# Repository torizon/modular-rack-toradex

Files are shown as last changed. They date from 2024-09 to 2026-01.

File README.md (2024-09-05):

# Modular rack for Toradex boards

This project was created using OpenSCAD, an open-source software for creating 3D CAD solids. With it, you can create a modular rack to stack any Toradex board, either vertically or horizontally. The internal dimensions of each support are adjusted according to the desired board, while the external dimensions remain the same, making it possible to stack these supports.

In the example below, we have the vertical stacking of two support models for Toradex Iris or Mallow boards. The visualization was created using the FreeCAD software.

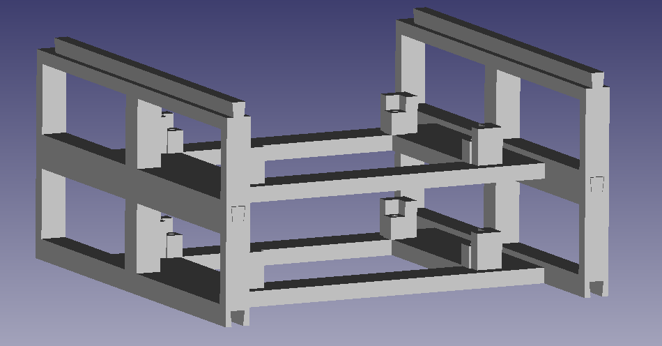
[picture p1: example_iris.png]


It is also possible to use these supports on their side, which significantly improves air circulation. In these cases, it is recommended to use the mounting holes to secure the boards with screws.

The figure below shows a CPU temperature comparison for the Toradex Verdin iMX8MP module, where the temperature differences are clearly noticeable when the rack is positioned vertically (one board on top of the other) or horizontally (one board next to the other).

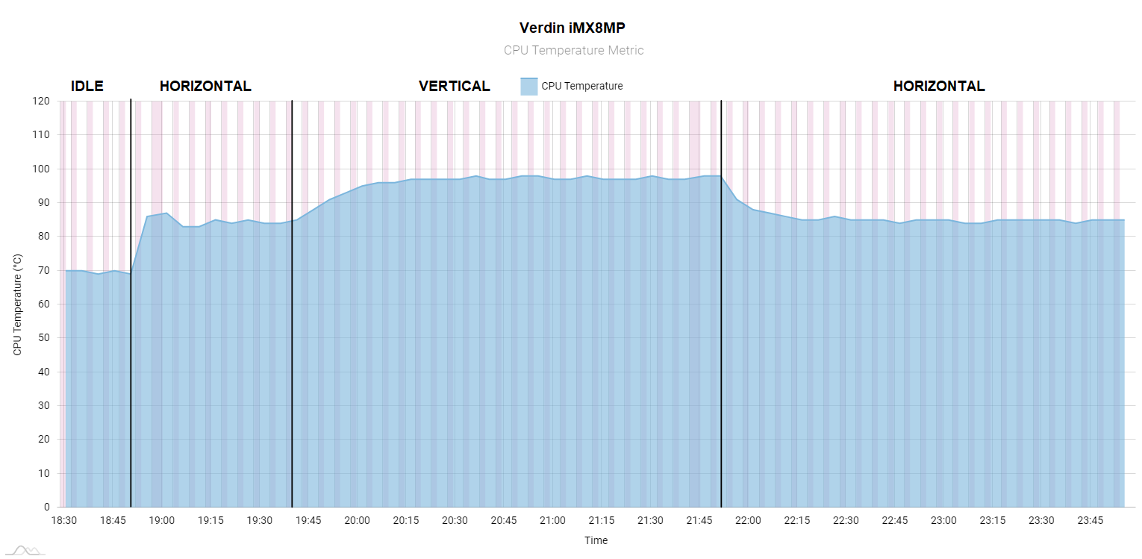
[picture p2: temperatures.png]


## How to use

To select your board, you must include the desired board on the first lines of `main.scad` file. The dimensions of each board can be found in the `boards_dimensions directory`. After that, export the STL file and use your preferred slicer to create the file for printing.

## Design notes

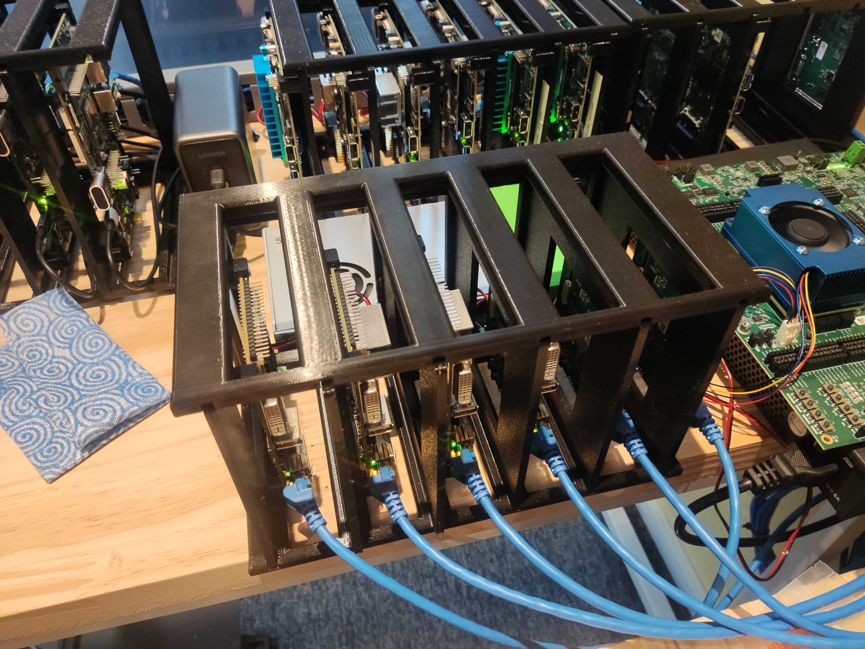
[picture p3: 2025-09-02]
v2/photos/example3.jpg

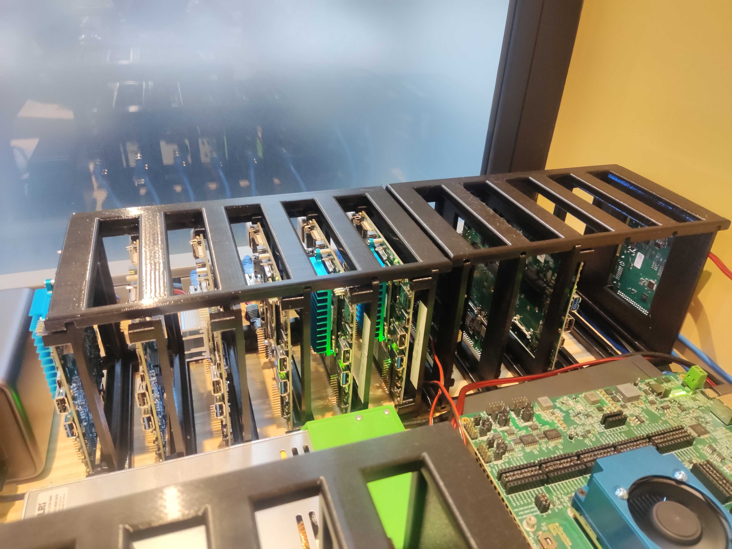
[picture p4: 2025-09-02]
v2/photos/example2.jpg

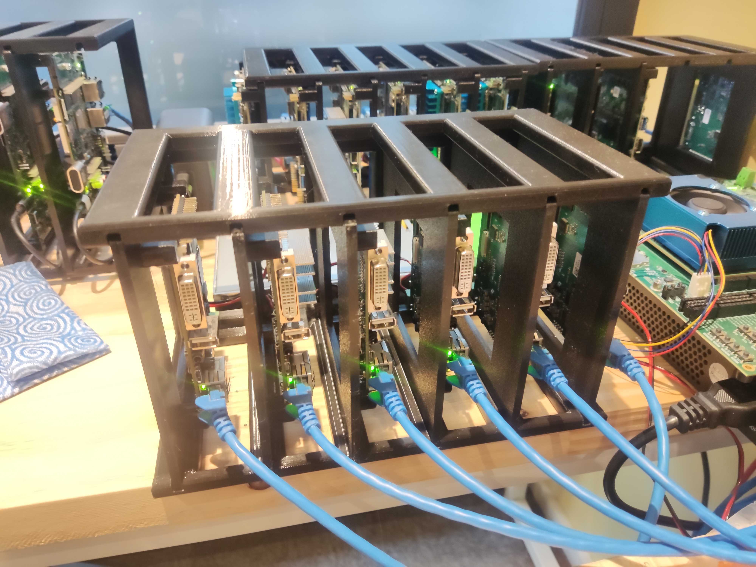
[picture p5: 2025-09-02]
v2/photos/example1.jpg

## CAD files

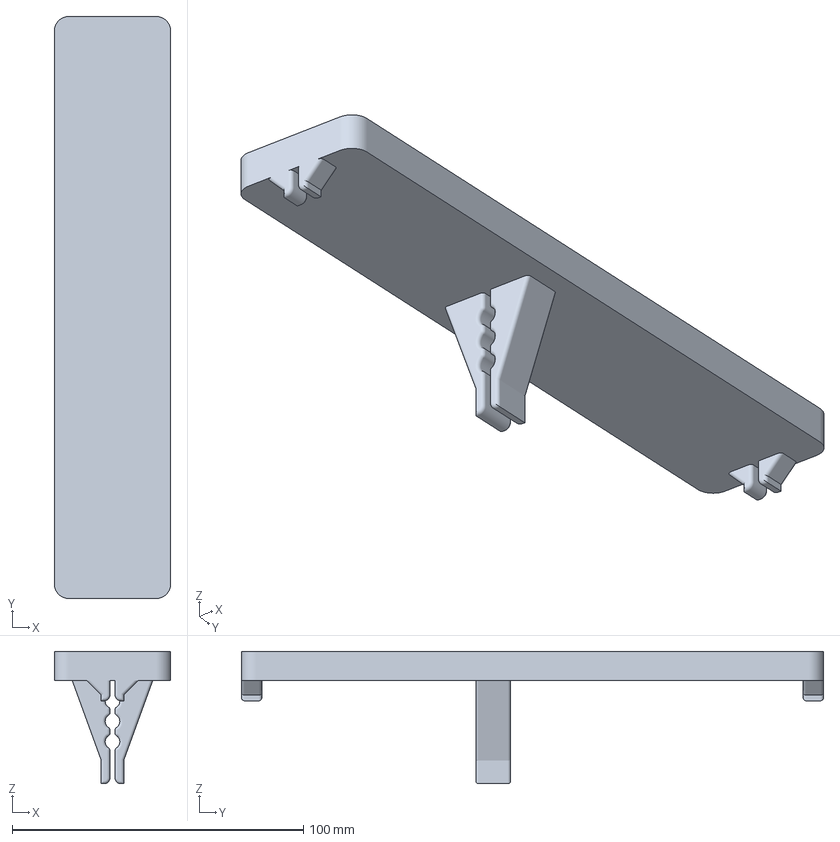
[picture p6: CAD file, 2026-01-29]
v2/smarc-devboard-aval-Body.3mf
40.0 x 200.0 x 45.5 mm

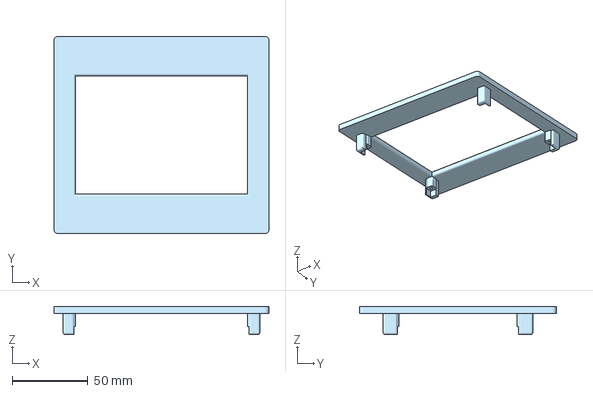
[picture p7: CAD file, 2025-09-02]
v2/ixora.3mf
141.6 x 129.7 x 18.6 mm

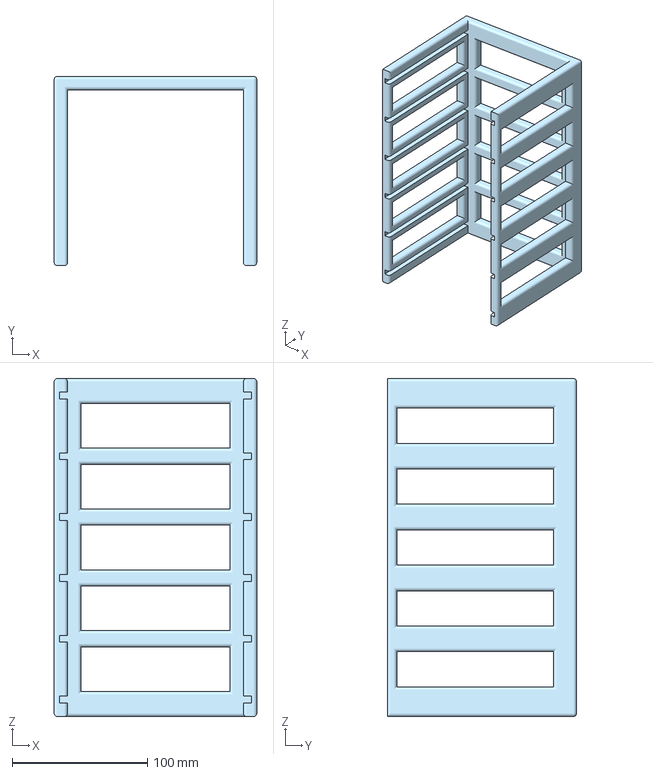
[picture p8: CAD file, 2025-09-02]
v2/rack.3mf
150.0 x 140.0 x 250.0 mm

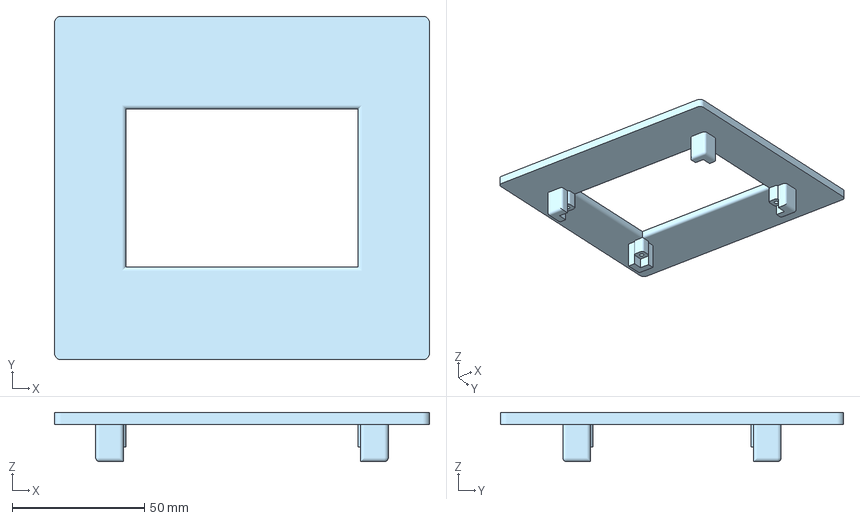
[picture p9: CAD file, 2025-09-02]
v2/iris_mallow.3mf
141.6 x 129.7 x 18.6 mm

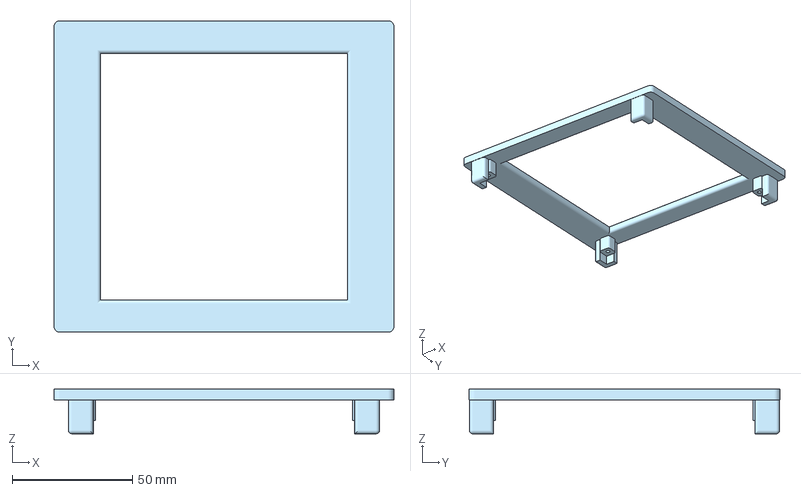
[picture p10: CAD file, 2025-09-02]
v2/yavia_dahlia_clover.3mf
141.6 x 129.7 x 18.6 mm

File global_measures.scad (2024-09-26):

// Board dimensions
external_length = 161;
external_width = 161;

wall_thickness_external = 10;
wall_thickness_internal = 5;

pin_width = 5.5;
hole_heigth = 6;

space_between_hole_pin = 0.20;

// Necessary to standard pins and holes, even though the height of the support is different
standard_height = 40;

// Total height of the support
total_height = 40;

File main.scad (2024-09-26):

// Select the board
include <boards_dimensions/boards.scad>

module hole_trapezium(height){
    linear_extrude(height = height){
        polygon(points=[[-3,hole_heigth],[-2.4, 0],[2.4, 0],[3,hole_heigth]]);
    }
}

module pin_trapezium(height){
    linear_extrude(height = height){
        polygon(points=[[-3 + space_between_hole_pin, hole_heigth - space_between_hole_pin],[-2.4 + space_between_hole_pin, 0],[2.4 - space_between_hole_pin, 0],[3 - space_between_hole_pin, hole_heigth - space_between_hole_pin]]);
    }
}

module test_extruder(){
    translate([60, 0, 0])
        cube([10000, 10000, 500]);

    translate([-10, 10, 0])
        cube([10000, 10000, 500]);

    translate([-10, 0, 0])
        cube([10000, 10000, 37]);

    // translate([-10, 0, 9])
    //     cube([10000, 10000, 10000]);
}

module support_without_screws() {
    distance_major_hole = 0.8*wall_thickness_external;
    distance_minor_hole = (wall_thickness_external - pin_width - 2*space_between_hole_pin)/2;

    // External box
    difference() {
        cube([external_length, external_width, total_height]);

        // Internal box
        translate([start_inside_cube_x, start_inside_cube_y, base_thickness])
            cube([internal_length, internal_width, total_height - base_thickness]);

        // Remove left wall
        translate([0, wall_thickness_external, base_thickness])
            cube([external_length, start_inside_cube_y - wall_thickness_external - wall_thickness_internal, total_height - base_thickness]);

        // Remove right wall
        translate([0, start_inside_cube_y + internal_width + wall_thickness_internal, base_thickness])
            cube([external_length, external_width - start_inside_cube_y - internal_width - wall_thickness_external - wall_thickness_internal, total_height - base_thickness]);

        // Remove back wall, including floor
        translate([0, wall_thickness_external, base_thickness])
            cube([start_inside_cube_x - wall_thickness_internal, external_width - 2*wall_thickness_external, total_height - base_thickness]);

        // Remove back wall, mantaining floor
        translate([0, wall_thickness_external, 0])
            cube([start_inside_cube_x - 2*wall_thickness_internal, external_width - 2*wall_thickness_external, total_height]);

        // Remove front wall, including floor
        translate([external_width - start_inside_cube_x + wall_thickness_internal, wall_thickness_external, base_thickness])
            cube([start_inside_cube_x - wall_thickness_internal, external_width - 2*wall_thickness_external, total_height - base_thickness]);

        // Remove front wall, mantaining floor
        translate([external_width - start_inside_cube_x + 2*wall_thickness_internal, wall_thickness_external, 0])
            cube([start_inside_cube_x - 2*wall_thickness_internal, external_width - 2*wall_thickness_external, total_height]);

        // Internal hole on the floor for board
        translate([start_inside_cube_x+base_size, start_inside_cube_y+base_size])
            cube([internal_length-2*base_size, internal_width-2*base_size, total_height - base_thickness]);

        // Remove front wall on internal box
        translate([start_inside_cube_x + internal_length, start_inside_cube_y + left_distance_front, base_thickness])
            cube([wall_thickness_internal, internal_width - left_distance_front - right_distance_front, total_height - base_thickness]);

        // Remove back wall on internal box
        translate([start_inside_cube_x - wall_thickness_internal, start_inside_cube_y + left_distance_back, base_thickness])
            cube([wall_thickness_internal, internal_width - left_distance_back - right_distance_back, total_height - base_thickness]);

        // Remove lateral walls on internal box
        translate([start_inside_cube_x + internal_lateral_thickness, wall_thickness_external, base_thickness])
            cube([internal_length - 2*internal_lateral_thickness, external_width -2*wall_thickness_external, total_height - base_thickness]);

        // Remove roof of internal box
        translate([0, wall_thickness_external, internal_heigth])
            cube([external_length, external_width - 2*wall_thickness_external, total_height - internal_heigth]);

        // Hole on the floor, left side
        translate([0, wall_thickness_external/2, 0]) rotate([90,0,90])
            hole_trapezium(external_length - wall_thickness_external);

        // Hole on the floor, right side
        translate([0, external_width - wall_thickness_external/2, 0]) rotate([90,0,90])
            hole_trapezium(external_length - wall_thickness_external);

        square_size = 70.5;
        space_between = 10;

        // First square hole on left side
        translate([0.5*space_between, 0, 1.35*base_thickness])
            cube([square_size, wall_thickness_external, total_height - 1/2*wall_thickness_external - 1.35*base_thickness]);

        // Second square hole on left side
        translate([1.5*space_between + square_size, 0, 1.35*base_thickness])
            cube([square_size, wall_thickness_external, total_height - 1/2*wall_thickness_external - 1.35*base_thickness]);

        // First square hole on right side
        translate([0.5*space_between, external_width - wall_thickness_external, 1.35*base_thickness])
            cube([square_size, wall_thickness_external, total_height - 1/2*wall_thickness_external - 1.35*base_thickness]);

        // Second square hole on right side
        translate([1.5*space_between + square_size, external_width - wall_thickness_external, 1.35*base_thickness])
            cube([square_size, wall_thickness_external, total_height - 1/2*wall_thickness_external - 1.35*base_thickness]);
    }

    // Pin on roof, left side
    translate([0, wall_thickness_external/2, total_height]) rotate([90,0,90])
        pin_trapezium(external_length - wall_thickness_external - space_between_hole_pin);

    // Pin on roof, right side
    translate([0, external_width - wall_thickness_external/2, total_height]) rotate([90,0,90])
        pin_trapezium(external_length - wall_thickness_external - space_between_hole_pin);

    // Foot back left
    translate([start_inside_cube_x, start_inside_cube_y, base_thickness])
        cube([foot_size, foot_size, foot_height]);

    // Foot back right
    translate([start_inside_cube_x, start_inside_cube_y + internal_width - foot_size, base_thickness])
        cube([foot_size, foot_size, foot_height]);

    // Foot front left
    translate([start_inside_cube_x + internal_length - foot_size, start_inside_cube_y, base_thickness])
        cube([foot_size, foot_size, foot_height]);

    // Foot front right
    translate([start_inside_cube_x + internal_length - foot_size, start_inside_cube_y + internal_width - foot_size, base_thickness])
        cube([foot_size, foot_size, foot_height]);
}

module support() {
    difference() {
        support_without_screws();

        // Screw hole, up left
        translate([start_inside_cube_x +  screw_distance_x, start_inside_cube_y +  screw_distance_y, base_thickness + foot_height - 3])  // Move slightly down to ensure a clean cut
            cylinder(h = 3, r = 1.2, $fn = 100);

        // Screw hole, down left
        translate([start_inside_cube_x + internal_length -  screw_distance_x, start_inside_cube_y +  screw_distance_y, base_thickness + foot_height - 3])  // Move slightly down to ensure a clean cut
            cylinder(h = 3, r = 1.2, $fn = 100);

        // Screw hole, up right
        translate([start_inside_cube_x +  screw_distance_x, start_inside_cube_y + internal_width -  screw_distance_y, base_thickness + foot_height - 3])  // Move slightly down to ensure a clean cut
            cylinder(h = 3, r = 1.2, $fn = 100);

        // Screw hole, down right
        translate([start_inside_cube_x + internal_length -  screw_distance_x, start_inside_cube_y + internal_width -  screw_distance_y, base_thickness + foot_height - 3])  // Move slightly down to ensure a clean cut
            cylinder(h = 3, r = 1.2, $fn = 100);

        // test_extruder();
    }
}

support();

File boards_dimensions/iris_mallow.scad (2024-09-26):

include <../global_measures.scad>

internal_length = 72.5;
internal_width = 100.5;

start_inside_cube_x = (external_length - internal_length)/2;
start_inside_cube_y = (external_width - internal_width)/2;

base_thickness = 6;
base_size = 5.5;
left_distance_front = 5.5;
right_distance_front = 5.5;
left_distance_back = 5.5;
right_distance_back = 5.5;
internal_lateral_thickness = 5.5;

foot_size = 6.4;
foot_height = 8.5;
internal_heigth = standard_height/2;

screw_distance_x = 3.25;
screw_distance_y = 3.25;

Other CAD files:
boards_dimensions/ixora.scad
boards_dimensions/raspberry_pi_4b.scad
boards_dimensions/seeed_studio.scad
boards_dimensions/yavia_dahlia.scad

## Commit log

2024-08-09 First idea of the project
    Note at this point, when you create a model for a small board, the walls
    became very thick
    [suporte_ide.scad]
2024-08-12 Add round edges to external cube
    [suporte_ide.scad]
2024-08-12 Increase wall thickness
    [suporte_ide.scad]
2024-08-12 Add the pins and holes to the front and the back
    [suporte_ide.scad]
2024-08-14 Remove unnecessary comments
    [suporte_ide.scad]
2024-08-14 Translate the comments
    [suporte_ide.scad]
2024-08-14 Fix the back wall of external box and walls of internal box
    [suporte_ide.scad]
2024-08-14 Remove left and right wall of internal box
    [suporte_ide.scad]
2024-08-14 Remove the roof of the internal box
    [suporte_ide.scad]
2024-08-14 Fix front
    [suporte_ide.scad]
2024-08-14 Add a condition to remove walls of internal box
    This helps when the internal box is very close to external box,
    resulting on erros
    [suporte_ide.scad]
2024-08-14 Add square holes on laterals
    [suporte_ide.scad]
2024-08-14 Add holes on the floor of lateral squares
    [suporte_ide.scad]
2024-08-14 Change the name of some variables
    Actually, this variables are been used as the newer name of them
    [suporte_ide.scad]
2024-08-15 Remove unnecessary case statement to remove internal walls
    [suporte_ide.scad]
2024-08-16 Separate the external and internal thickness and increase external
    [suporte_ide.scad]
2024-08-16 Increase pin width
    [suporte_ide.scad]
2024-08-16 Change from pin/hole to slide on vertical stack
    [suporte_ide.scad]
2024-08-16 Separate the thicknes of the internal walls
    [suporte_ide.scad]
2024-08-20 Increase external size to fit bigger boards
    [suporte_ide.scad]
2024-08-20 Change the cube slide to a trapezium slide
    [suporte_ide.scad]
2024-08-20 Add a test module to project
    [suporte_ide.scad]
2024-08-20 Add a foot to internal box
    [suporte_ide.scad]
2024-08-20 Remove the unnecessary floor of the internal box
    [suporte_ide.scad]
2024-08-20 Fix removal of roof variables
    This occur when internal and external box are very close to each other,
    causing a bug when removing the roof
    [suporte_ide.scad]
2024-08-20 Change the size of base size
    [suporte_ide.scad]
2024-08-20 Add the size of internal box as parameters of support
    [suporte_ide.scad]
2024-08-20 Use Iris as measure example
    [suporte_ide.scad]
2024-08-21 Increase thickness and size of base to improve hardness
    [suporte_ide.scad]
2024-08-21 Create a folder containing boards parameters taht could be selected
    [iris.scad, suporte_ide.scad, yavia.scad]
2024-08-23 Fix floating of floor pins, causing low adhesion
    [suporte_ide.scad]
2024-08-23 Pass the height of trapezium as a parameter
    [suporte_ide.scad]
2024-08-27 Fix identation
    [suporte_ide.scad]
2024-08-27 Add the mallow to the name of iris, they have the same dimensions
    [iris_mallow.scad]
2024-08-30 Increase the size of square holes on lateral
    [suporte_ide.scad]
2024-08-30 Add some parameters to boards file instead of main file
    [iris_mallow.scad, suporte_ide.scad, yavia.scad]
2024-08-30 Add a dimension file to odyssey seeed studio board
    [seed_studio.scad]
2024-08-30 Rename the main file of project
    [main.scad]
2024-08-30 Fix height variables of cube that remove the floor
    Related-to: TCCP-813
    [main.scad]
2024-08-30 Add Ixora dimensions to project
    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
    [ixora.scad]
2024-08-30 Fix the name of Odyssey Seed Studio board
    [seeed_studio.scad]
2024-08-30 Add a standard height, to be used for other variables
    [ixora.scad, main.scad]
2024-09-03 Change the for statement for holes to manual one
    This way, it's easier to understand what is happening and easier to do
    custom changes on the model
    [main.scad]
2024-09-03 Add standard height to boards_dimension files
    [iris_mallow.scad, ixora.scad, seeed_studio.scad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]
2024-09-03 Create a module for screw holes on support
    [main.scad]
2024-09-03 Increase foot size to fit screw hole
    [iris_mallow.scad, ixora.scad, seeed_studio.scad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]
2024-09-03 Put variable on boards dimensions to screw distance
    [iris_mallow.scad, ixora.scad, main.scad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]
2024-09-03 Fix the value of internal_heigth attribution
    [iris_mallow.scad, ixora.scad, seeed_studio.scad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]
2024-09-03 Reduce the internal_height of the boards
    This way, it's possible the remove the boards from the support without
    moving the support itself.
    [iris_mallow.scad, seeed_studio.scad, yavia.scad]
2024-09-03 Decrese the radius of hole screws
    This was made because it's decided to use metal screws, so decreasing
    the hole make possible to create the hole using the screw. Finally, the
    holes on the 3D model are working just like a guide.
    [main.scad]
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2024-09-03 Increase height os seeed_studio
    [seeed_studio.scad]
2024-09-03 Fix a instruction to select the board on README
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2024-09-05 Remove the fitting holes on lateral holes
    [main.scad]
2024-09-05 Increase size of lateral holes
    [main.scad]
2024-09-09 Increase space between hole and pin, since it was very tight
    [main.scad]
2024-09-09 Fix typo on space_between_hole_pin variable
    [main.scad]
2024-09-17 Increase size of screw holes
    This way, the screws enter easily on the plastic
    [main.scad]
2024-09-23 Remove pins and holes in front and back
    [main.scad]
2024-09-26 Make remove right wall statements more generic, to accept more boards
    [iris_mallow.scad, ixora.scad, main.scad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]
2024-09-26 Add raspberry pi 4b model
    [raspberry_pi_4b.scad]
2024-09-26 Put the common variable on global_measures.scad file
    [global_measures.scad, iris_mallow.scad, ixora.scad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]
2024-10-01 Rename yavia file, since it's also compatible with dahlia
    [yavia_dahlia.scad]
2025-09-02 Add v2 version of rack
    [iris_mallow.3mf, ixora.3mf, rack.3mf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]
2026-01-29 Add vertical holder for Toradex SMARC Development Board
    [smarc-devboard-aval-Body.3mf]
